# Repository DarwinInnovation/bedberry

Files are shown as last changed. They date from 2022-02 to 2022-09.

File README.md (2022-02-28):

# bedberry

PCB for intelligent electric bed/chair control. A board to allow those with disabilities
a number of ways to control electric beds, chairs etc.

Based around the [Raspberry Pi Zero 2W](https://www.raspberrypi.com/products/raspberry-pi-zero-2-w/) it is designed to allow abilities such as:

- Voice service (e.g. Alexa) control of the bed.
- Control of all the bed's function from simple buttons or pressure pads.
- Link to BLE tilt sensors to allow bed position 'presets'.
- Control of other devices via bluetooth, IR or WiFi, including TVs, lights, SwitchBots etc.

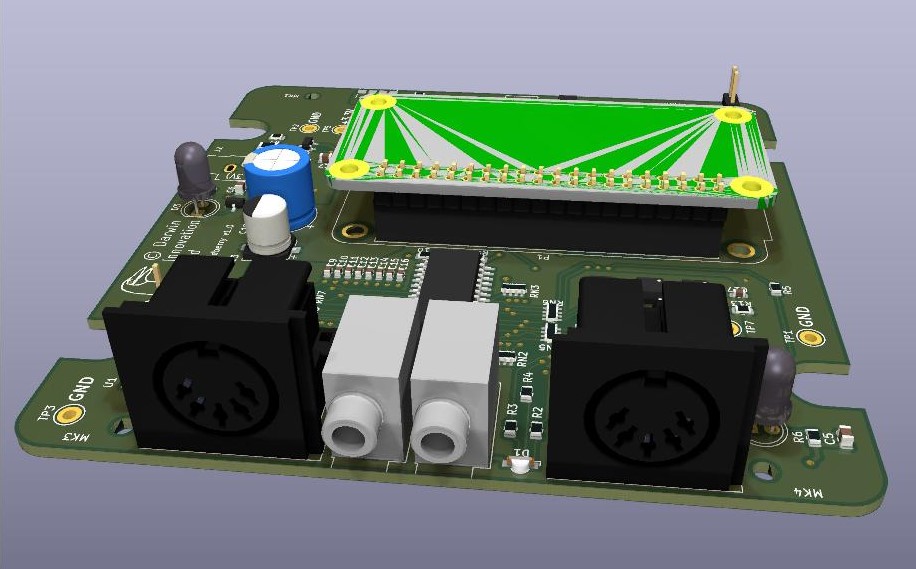
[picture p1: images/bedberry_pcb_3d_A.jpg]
3D Render of PCB


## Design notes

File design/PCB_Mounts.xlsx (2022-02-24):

Origin | 200 | 150
Case |  |  | 10.16
Diff Inch | 2.4 | 3.6
Diff mm | 60.96 | 91.44
 | 169.52 | 104.28
 | 230.48 | 104.28
 | b | 195.72
 | 230.48 | 195.72
PCB
Diff Inch | 3.6 | 2.9
Diff mm | 91.44 | 73.66
 | 154.28 | 113.17
 | 245.72 | 113.17
 | 154.28 | 186.83
 | 245.72 | 186.83

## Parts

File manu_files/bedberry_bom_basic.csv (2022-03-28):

Ref | Qnty | Value | Footprint | Description | MPN
C1, | 1 | 1nF 0805 | Capacitor_SMD:C_0805_2012Metric | Unpolarized capacitor, small symbol
C2, C4, C8, C9, C10, C11, C12, C13, C14, C15, C16, C17, C18, C20, | 14 | 100nF 0603 | Capacitor_SMD:C_0603_1608Metric | Unpolarized capacitor, small symbol
D1, | 1 | KPFA-3010RGBC-11 | LED_SMD:LED_Kingbright_APFA3010_3x1.5mm_Horizontal | LED RGB, Common Anode, SMD, 3.0x1.5mm, Horizontal | KPFA-3010RGBC-11
F1, | 1 | MP005240 | Fuse:Fuse_1812_4532Metric | Resettable fuse, polymeric positive temperature coefficient, small symbol | MP005240
F2, | 1 | 1206L150THWR | Fuse:Fuse_1206_3216Metric | Resettable fuse, polymeric positive temperature coefficient, small symbol | 1206L150THWR
J1, | 1 | USB Micro-B | Connector_USB:USB_Micro-B_Amphenol_10118194_Horizontal | USB Micro Type B connector | 10118194-0001LF
JP1, | 1 | Jumper | Connector_PinHeader_2.54mm:PinHeader_1x03_P2.54mm_Vertical | Jumper, 3-pole, pins 1+2 closed/bridged | M20-8770342
JP2, | 1 | Jumper_2_Open | Connector_PinHeader_2.54mm:PinHeader_1x02_P2.54mm_Vertical | Jumper, 2-pole, open
Q1, Q3, | 2 | BC817 SOT23 | Package_TO_SOT_SMD:SOT-23 | 0.8A Ic, 45V Vce, NPN Transistor, SOT-23 | BC817-25LT1G
Q2, | 1 | MOSFET P-Ch SOT23 | Package_TO_SOT_SMD:SOT-23 | -6.4A Id, -40V Vds, P-Channel MOSFET, SOT-223 | DMG2307L-7
R1, R13, R15, | 3 | 1M 0805 | Resistor_SMD:R_0805_2012Metric | Resistor
R2, | 1 | 120 0805 | Resistor_SMD:R_0805_2012Metric | Resistor
R3, R4, R6, R9, R14, | 5 | 5.6 0805 | Resistor_SMD:R_0805_2012Metric | Resistor
R5, R8, R16, R17, R18, | 5 | 1k 0805 | Resistor_SMD:R_0805_2012Metric | Resistor
R7, R10, R11, R12, | 4 | 10k 0805 | Resistor_SMD:R_0805_2012Metric | Resistor
RN1, RN2, RN3, RN4, | 4 | 10k 4x0603 | Resistor_SMD:R_Array_Concave_4x0603 | 4 resistor network, parallel topology | EXBV8V103JV
RN5, RN6, RN7, RN8, | 4 | 1.5k 4x0603 | Resistor_SMD:R_Array_Concave_4x0603 | 4 resistor network, parallel topology | EXB-38V152JV
U2, | 1 | MCP23017-E/SO | Package_SO:SOIC-28W_7.5x17.9mm_P1.27mm | 16-bit I/O expander, I2C, interrupts, w pull-ups, SSOP-28 | MCP23017-E/SO
U3, U4, U5, U6, U7, U8, U9, U10, | 8 | CPC1017N | Package_SO:SOP-4_3.8x4.1mm_P2.54mm | Form A, Solid State Relay (Photo MOSFET) 60V, 0.1A, 16Ohm, SO-4 | CPC1017NTR
U11, | 1 | CAT24C128 | Package_SO:SOIC-8_3.9x4.9mm_P1.27mm | 128 kb CMOS Serial EEPROM, SOIC-8/TSSOP-8/DFN-8 | CAT24C128WI-GT3

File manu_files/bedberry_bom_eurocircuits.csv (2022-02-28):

Source: | D:\Projects\bedberry\kicad\bedberry.kicad_sch
Date: | 28/02/2022 17:05:20
Tool: | Eeschema (6.0.1)
Generator: | C:\Users\richa\Documents\KiCad\6.0\scripting\plugins/bom_csv_eurocircuits.py
Component Count: | 87
Ref | Qnty | Value | Cmp name | Footprint | Description | Vendor
C1, | 1 | 1nF 0805 | GPC0805102 | Capacitor_SMD:C_0805_2012Metric | Unpolarized capacitor, small symbol
C2, C4, C8, C9, C10, C11, C12, C13, C14, C15, C16, C17, C18, C20, | 14 | 100nF 0603 | GPC0603104 | Capacitor_SMD:C_0603_1608Metric | Unpolarized capacitor, small symbol
C3, | 1 | 100uF SMD | C_Polarized_Small | Capacitor_SMD:CP_Elec_6.3x7.7 | Polarized capacitor, small symbol
C5, C6, C7, | 3 | 1uF 0805 | GPC0805105 | Capacitor_SMD:C_0805_2012Metric | Unpolarized capacitor, small symbol
C19, | 1 | 100uF 10mm TH | C_Polarized_Small | Capacitor_THT:CP_Radial_D10.0mm_P5.00mm | Polarized capacitor, small symbol
D1, | 1 | KPFA-3010RGBC-11 | KPFA-3010RGBC-11 | LED_SMD:LED_Kingbright_APFA3010_3x1.5mm_Horizontal | LED RGB, Common Anode, SMD, 3.0x1.5mm, Horizontal
D2, D3, | 2 | SFH4546 | LTE-4206 | LED_THT:LED_D5.0mm_IRGrey | High-Power IR LED 940nm
F1, | 1 | MP005240 | MP005240 | Fuse:Fuse_1812_4532Metric | Resettable fuse, polymeric positive temperature coefficient, small symbol
F2, | 1 | 1206L150THWR | 1206L150THWR | Fuse:Fuse_1206_3216Metric | Resettable fuse, polymeric positive temperature coefficient, small symbol
J1, | 1 | USB Micro-B | 10118194-0001LF | Connector_USB:USB_Micro-B_Amphenol_10118194_Horizontal | USB Micro Type B connector
J2, J5, J6, J7, | 4 | SJ1-3533NG | SJ1-3533NG | Connector_Audio:Jack_3.5mm_CUI_SJ1-3533NG_Horizontal | Audio Jack, 3 Poles (Stereo / TRS)
J3, J4, | 2 | DIN-7 | PSG03465 | wheelberry:pro-signal_DIN7_Socket | 7-pin DIN connector
JP1, | 1 | Jumper | M20-8770342 | Connector_PinHeader_2.54mm:PinHeader_1x03_P2.54mm_Vertical | Jumper, 3-pole, pins 1+2 closed/bridged
JP2, | 1 | Jumper_2_Open | Jumper_2_Open | Connector_PinHeader_2.54mm:PinHeader_1x02_P2.54mm_Vertical | Jumper, 2-pole, open
MK1, MK2, MK3, MK4, | 4 | M2.5 | MountingHole | MountingHole:MountingHole_2.7mm_M2.5 | Mounting Hole without connection
P1, | 1 | RPi Zero 2 W | A-BL254-DG-G40D | wheelberry:Raspberry_Pi_Zero_2W_Socketed_THT_FaceDown_MountingHoles | Generic connector, double row, 02x20, odd/even pin numbering scheme (row 1 odd numbers, row 2 even numbers), script generated (kicad-library-utils/schlib/autogen/connector/)
Q1, Q3, | 2 | BC817 | BC817-25LT1G | Package_TO_SOT_SMD:SOT-23 | 0.8A Ic, 45V Vce, NPN Transistor, SOT-23
Q2, | 1 | MOSFET P-Ch | DMG2307L | Package_TO_SOT_SMD:SOT-23 | -6.4A Id, -40V Vds, P-Channel MOSFET, SOT-223
R1, R13, R15, | 3 | 1M | GPR08051M | Resistor_SMD:R_0805_2012Metric | Resistor
R2, | 1 | 120 | GPR0805120R | Resistor_SMD:R_0805_2012Metric | Resistor
R3, R4, R6, R9, R14, | 5 | 5.6 | GPR08055R6 | Resistor_SMD:R_0805_2012Metric | Resistor
R5, R8, R16, R17, R18, | 5 | 1k | GPR08051K | Resistor_SMD:R_0805_2012Metric | Resistor
R7, R10, R11, R12, | 4 | 10k | GPR080510K | Resistor_SMD:R_0805_2012Metric | Resistor
RN1, RN2, RN3, RN4, | 4 | 10k | EXBV8V103JV | Resistor_SMD:R_Array_Concave_4x0603 | 4 resistor network, parallel topology
RN5, RN6, RN7, RN8, | 4 | 1.5k | EXB-38V152JV | Resistor_SMD:R_Array_Concave_4x0603 | 4 resistor network, parallel topology
TP1, TP2, TP3, TP4, TP5, TP6, TP7, TP8, | 8 | TestPoint | 5006 | TestPoint:TestPoint_Keystone_5005-5009_Compact | test point
U1, | 1 | TSOP382xx | TSOP38238 | OptoDevice:Vishay_MINICAST-3Pin | Photo Modules for PCM Remote Control Systems
U2, | 1 | MCP23017-E/SO | MCP23017-E/SO | Package_SO:SOIC-28W_7.5x17.9mm_P1.27mm | 16-bit I/O expander, I2C, interrupts, w pull-ups, SSOP-28
U3, U4, U5, U6, U7, U8, U9, U10, | 8 | CPC1017N | CPC1017NTR | Package_SO:SOP-4_3.8x4.1mm_P2.54mm | Form A, Solid State Relay (Photo MOSFET) 60V, 0.1A, 16Ohm, SO-4
U11, | 1 | CAT24C128 | CAT24C128WI-GT3 | Package_SO:SOIC-8_3.9x4.9mm_P1.27mm | 128 kb CMOS Serial EEPROM, SOIC-8/TSSOP-8/DFN-8

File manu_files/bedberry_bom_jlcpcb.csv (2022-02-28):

Comment | Designator | Footprint | LCSC
1nF 0805 | C1 | Capacitor_SMD:C_0805_2012Metric | C46653
100nF 0603 | C2, C4, C9, C10, C11, C12, C13, C14, C15, C16, C17, C18, C20 | Capacitor_SMD:C_0603_1608Metric | C14663
100uF SMD | C3 | Capacitor_SMD:CP_Elec_6.3x7.7
1uF 0805 | C5, C6, C7 | Capacitor_SMD:C_0805_2012Metric | C28323
100nF 0603 | C8 | Capacitor_SMD:C_0603_1608Metric | C14663
100uF 10mm TH | C19 | Capacitor_THT:CP_Radial_D10.0mm_P5.00mm
KPFA-3010RGBC-11 | D1 | LED_SMD:LED_Kingbright_APFA3010_3x1.5mm_Horizontal
SFH4546 | D2, D3 | LED_THT:LED_D5.0mm_IRGrey
MP005240 | F1 | Fuse:Fuse_1812_4532Metric | C55996
1206L150THWR | F2 | Fuse:Fuse_1206_3216Metric | C209741
USB Micro-B | J1 | Connector_USB:USB_Micro-B_Amphenol_10118194_Horizontal | C132563
SJ1-3533NG | J2, J5, J6 | Connector_Audio:Jack_3.5mm_CUI_SJ1-3533NG_Horizontal
DIN-7 | J3, J4 | wheelberry:pro-signal_DIN7_Socket
SJ1-3533NG | J7 | Connector_Audio:Jack_3.5mm_CUI_SJ1-3533NG_Horizontal
Jumper | JP1 | Connector_PinHeader_2.54mm:PinHeader_1x03_P2.54mm_Vertical
Jumper_2_Open | JP2 | Connector_PinHeader_2.54mm:PinHeader_1x02_P2.54mm_Vertical
M2.5 | MK1, MK2, MK3, MK4 | MountingHole:MountingHole_2.7mm_M2.5
RPi Zero 2 W | P1 | wheelberry:Raspberry_Pi_Zero_2W_Socketed_THT_FaceDown_MountingHoles
BC817 | Q1, Q3 | Package_TO_SOT_SMD:SOT-23 | C39828
MOSFET P-Ch | Q2 | Package_TO_SOT_SMD:SOT-23 | C102620
1M | R1, R13, R15 | Resistor_SMD:R_0805_2012Metric | C17514
120 | R2 | Resistor_SMD:R_0805_2012Metric | C17437
5.6 | R3, R4, R6, R9, R14 | Resistor_SMD:R_0805_2012Metric | C25321
1k | R5, R8, R16, R17, R18 | Resistor_SMD:R_0805_2012Metric | C17513
10k | R7, R10, R11, R12 | Resistor_SMD:R_0805_2012Metric | C17414
10k | RN1, RN2, RN3, RN4 | Resistor_SMD:R_Array_Concave_4x0603 | C109324
1.5k | RN5, RN6, RN7, RN8 | Resistor_SMD:R_Array_Concave_4x0603 | C11988
TestPoint | TP1, TP2, TP3, TP4, TP5, TP6, TP7, TP8 | TestPoint:TestPoint_Keystone_5005-5009_Compact
TSOP382xx | U1 | OptoDevice:Vishay_MINICAST-3Pin
MCP23017-E/SO | U2 | Package_SO:SOIC-28W_7.5x17.9mm_P1.27mm
CPC1017N | U3, U4, U5, U6, U7, U8, U9, U10 | Package_SO:SOP-4_3.8x4.1mm_P2.54mm | C81521
CAT24C128 | U11 | Package_SO:SOIC-8_3.9x4.9mm_P1.27mm | C81195

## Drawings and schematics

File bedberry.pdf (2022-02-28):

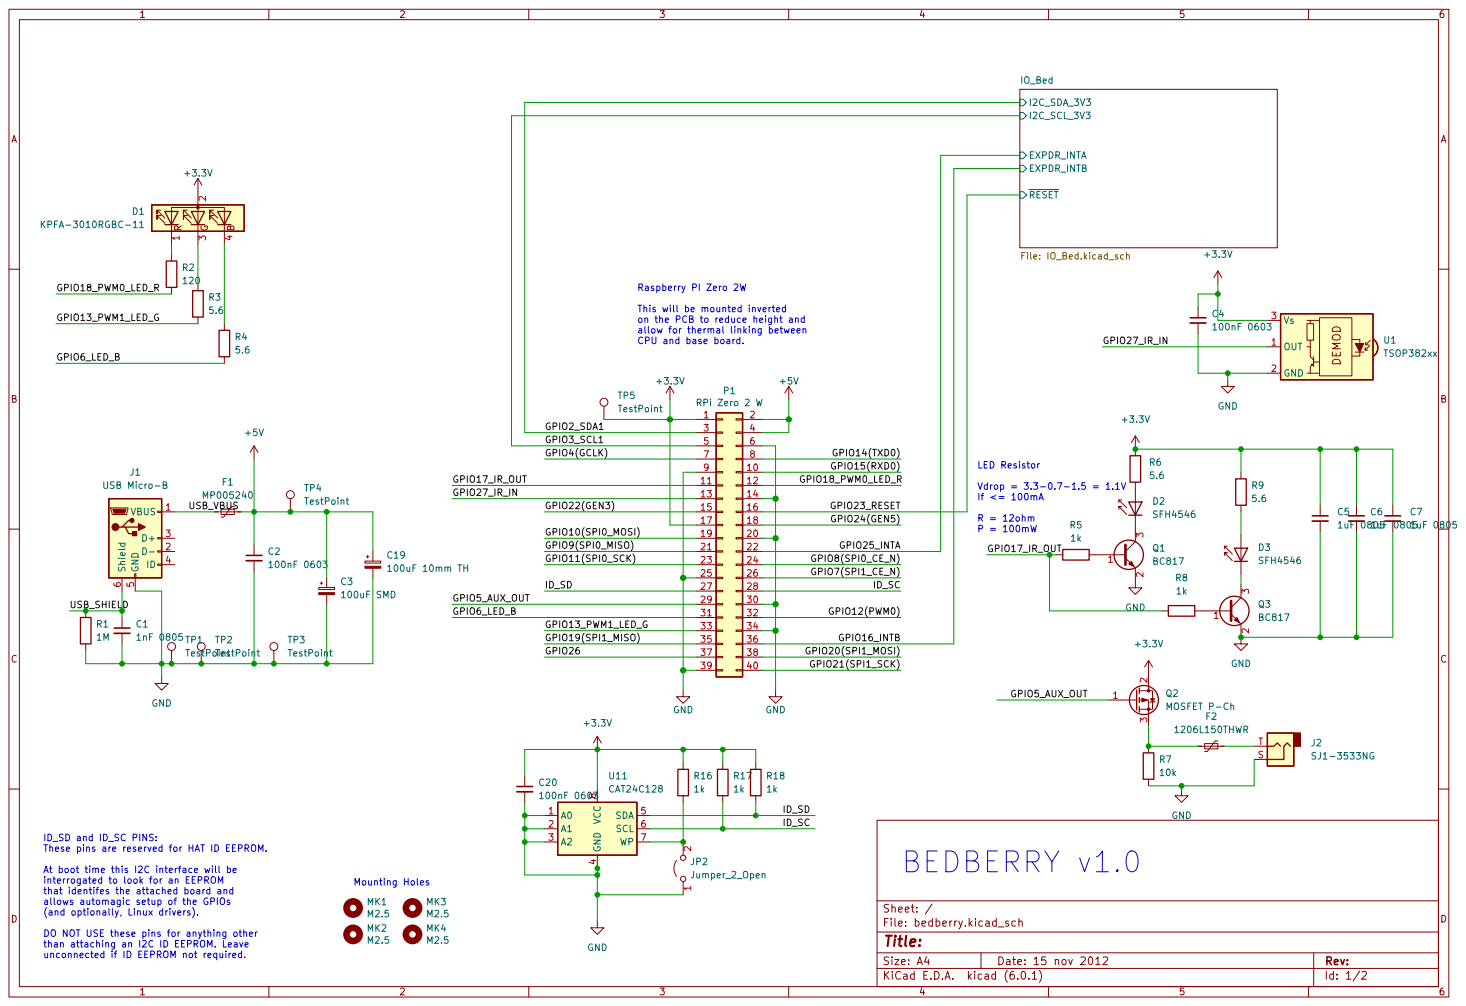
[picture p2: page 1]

This will be mounted inverted
on the PCB to reduce height and
+3.3VGND

4 SDA 5 SCL 6 WP 7 VCC

ID_SD and ID_SC PINS: These pins are reserved for HAT ID EEPROM. At boot time this I2C interface will be

interrogated to look for an EEPROM
that identifes the attached board and
allows automagic setup of the GPIOs
(and optionally, Linux drivers).
DO NOT USE these pins for anything other
than attaching an I2C ID EEPROM. Leave
unconnected if ID EEPROM not required.

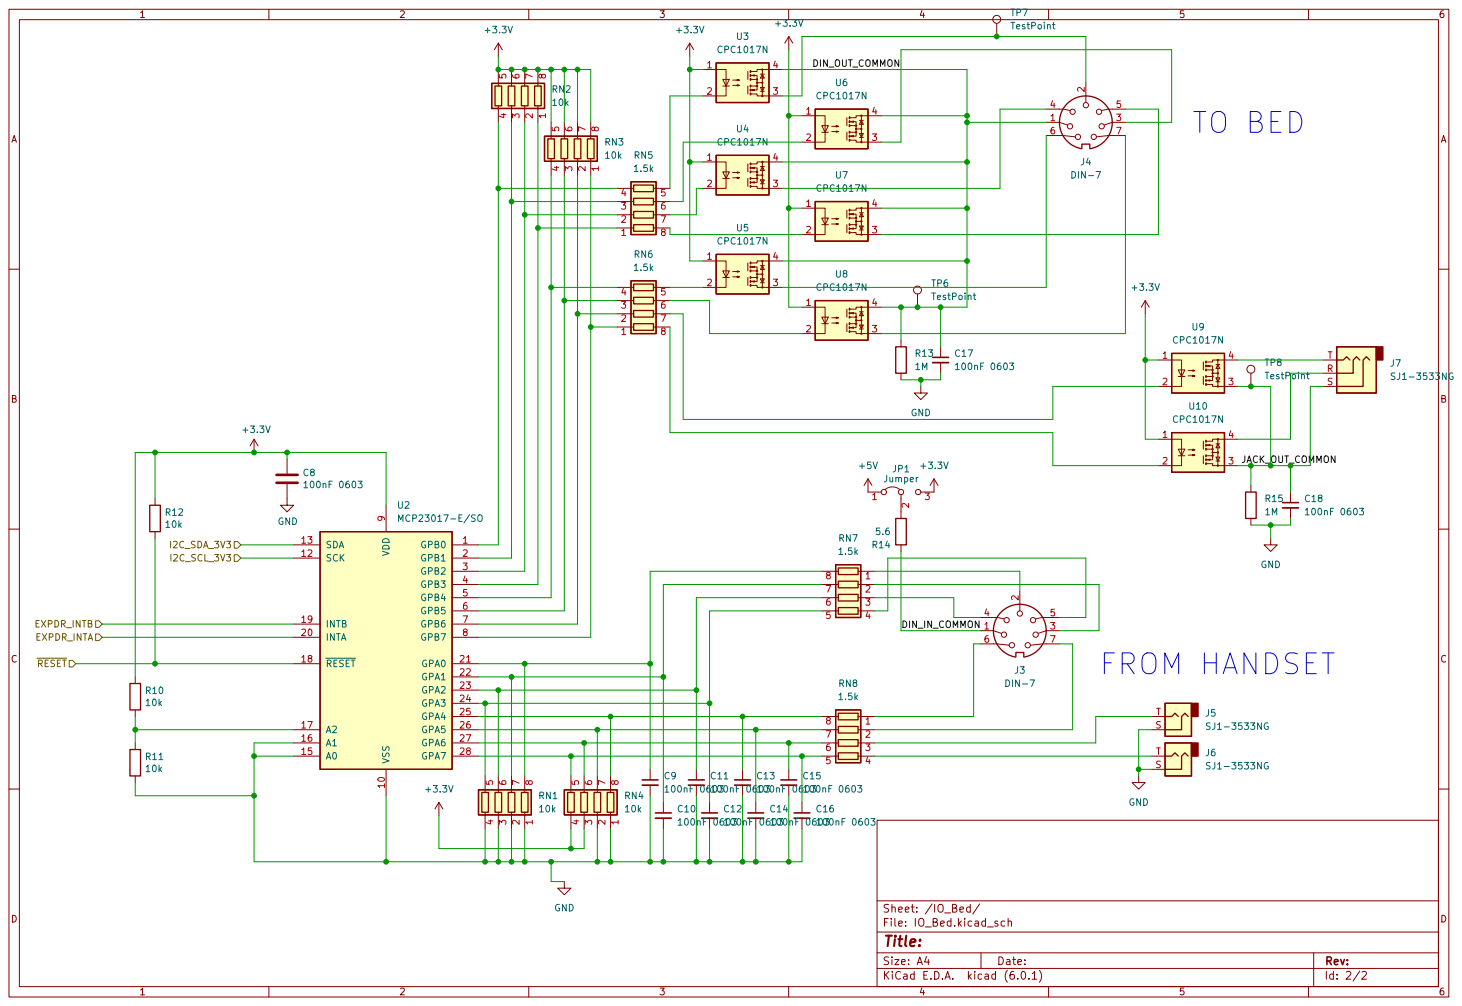
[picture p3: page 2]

4 U7 CPC1017N

4 U8 CPC1017N

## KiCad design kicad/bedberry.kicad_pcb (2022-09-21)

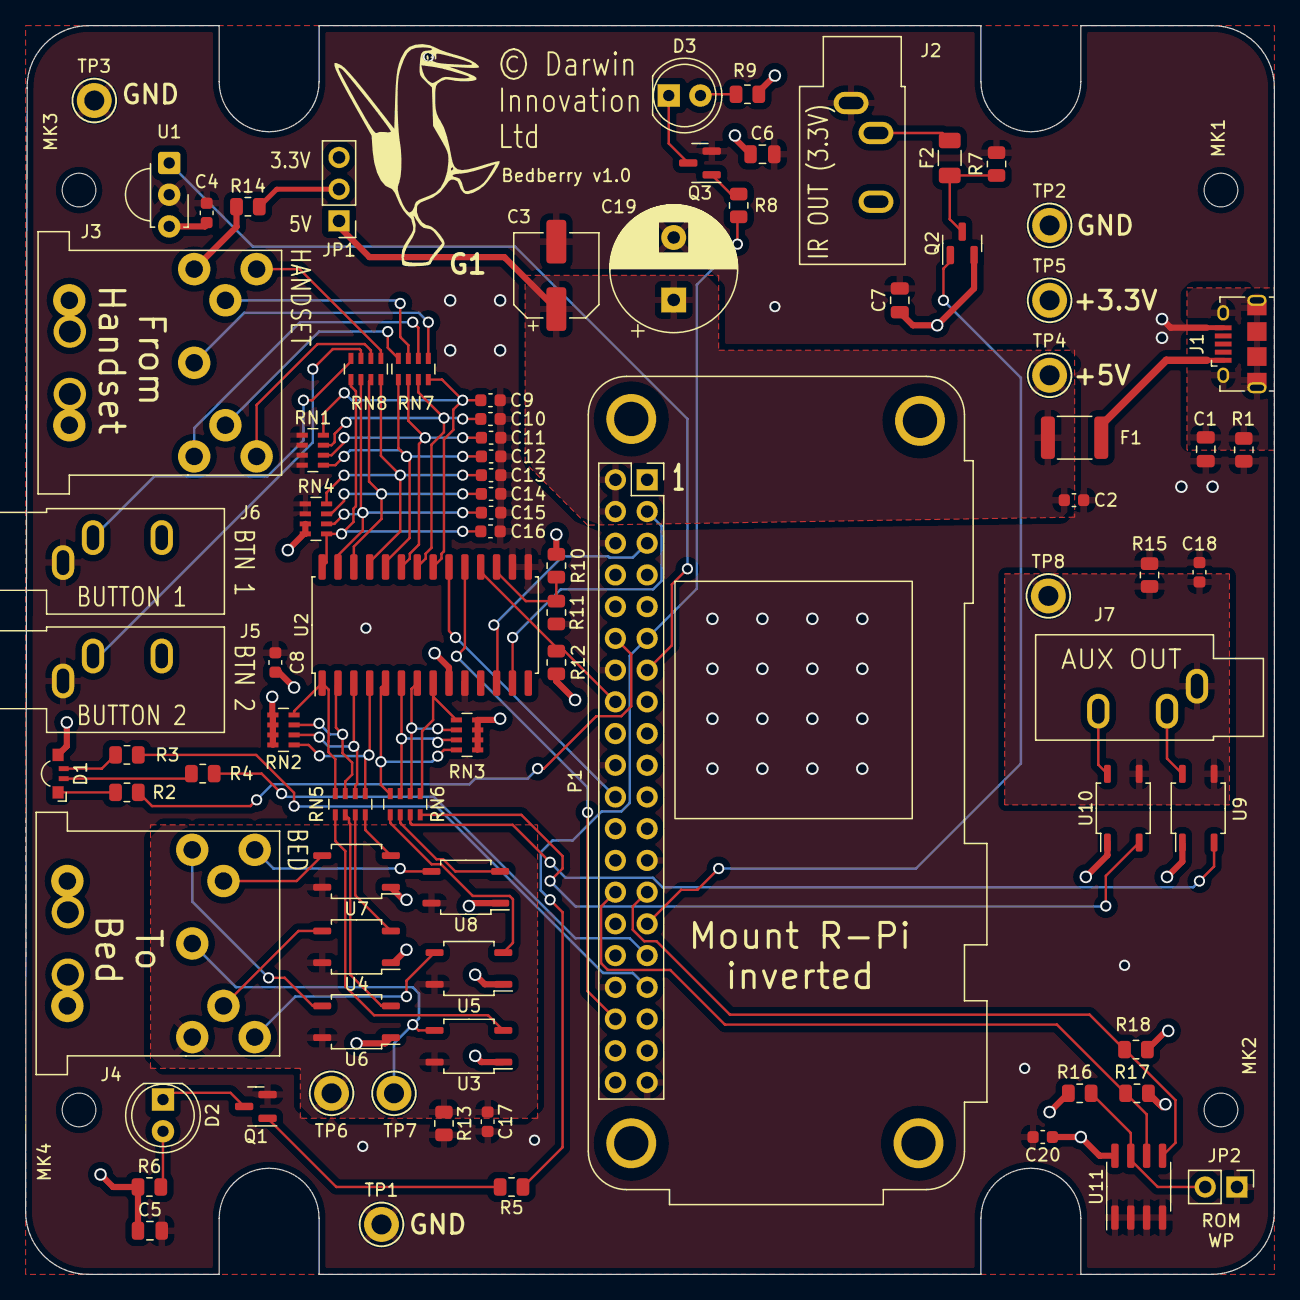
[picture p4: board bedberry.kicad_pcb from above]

Board: 4 copper layers, 100.0 x 100.0 mm, 88 parts (0 on the bottom side), 75 nets.

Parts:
C1: 1nF 0805; C_0805_2012Metric
C2, C4, C8, C9, C10, C11, C12, C13, C14, C15, C16, C17, C18, C20: 100nF 0603; C_0603_1608Metric
C3: 100uF SMD; CP_Elec_6.3x7.7
C5, C6, C7: 1uF 0805; C_0805_2012Metric
C19: 100uF 10mm TH; CP_Radial_D10.0mm_P5.00mm
D1: KPFA-3010RGBC-11; LED_Kingbright_APFA3010_3x1.5mm_Horizontal
D2, D3: SFH4546; LED_D5.0mm_IRGrey
F1: MP005240; Fuse_1812_4532Metric
F2: 1206L150THWR; Fuse_1206_3216Metric
G1: LOGO; darwin_innovation_logo
J1: USB Micro-B; USB_Micro-B_Amphenol_10118194_Horizontal
J2, J5, J6, J7: SJ1-3533NG; Jack_3.5mm_CUI_SJ1-3533NG_Horizontal
J3, J4: DIN-7; pro-signal_DIN7_Socket
JP1: Jumper; PinHeader_1x03_P2.54mm_Vertical
JP2: Jumper_2_Open; PinHeader_1x02_P2.54mm_Vertical
MK1, MK2, MK3, MK4: M2.5; MountingHole_2.7mm_M2.5
P1: RPi Zero 2 W; Raspberry_Pi_Zero_2W_Socketed_THT_FaceDown_MountingHoles
Q1, Q3: BC817; SOT-23
Q2: MOSFET P-Ch; SOT-23
R1, R13, R15: 1M; R_0805_2012Metric
R2: 120; R_0805_2012Metric
R3, R4, R6, R9, R14: 5.6; R_0805_2012Metric
R5, R8, R16, R17, R18: 1k; R_0805_2012Metric
R7, R10, R11, R12: 10k; R_0805_2012Metric
RN1, RN2, RN3, RN4: 10k; R_Array_Concave_4x0603
RN5, RN6, RN7, RN8: 1.5k; R_Array_Concave_4x0603
TP1, TP2, TP3, TP4, TP5, TP6, TP7, TP8: TestPoint; TestPoint_Keystone_5005-5009_Compact
U1: TSOP382xx; Vishay_MINICAST-3Pin
U2: MCP23017-E/SO; SOIC-28W_7.5x17.9mm_P1.27mm
U3, U4, U5, U6, U7, U8, U9, U10: CPC1017N; SOP-4_3.8x4.1mm_P2.54mm
U11: CAT24C128; SOIC-8_3.9x4.9mm_P1.27mm

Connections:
+3V3: C4.1, C5.1, C6.1, C7.1, C8.1, C20.1, D1.2 (A), JP1.3 (B), P1.1, P1.17, Q2.2 (D), R6.1, R9.1, R10.1, R12.1, R16.1, R17.1, R18.1, RN2.5 (R4.2), RN2.6 (R3.2), RN2.7 (R2.2), RN2.8 (R1.2), RN3.5 (R4.2), RN3.6 (R3.2), RN3.7 (R2.2), RN3.8 (R1.2), RN4.3 (R3.1), RN4.4 (R4.1), TP5.1, U1.3 (Vs), U2.9 (VDD), U3.1, U4.1, U5.1, U6.1, U7.1, U8.1, U9.1, U10.1, U11.8 (VCC)
+5V: C2.1, C3.1, C19.1, F1.2, JP1.1 (A), P1.2, P1.4, TP4.1
/GPIO2_SDA1: P1.3, U2.13 (SDA)
/GPIO3_SCL1: P1.5, U2.12 (SCK)
/GPIO5_AUX_OUT: P1.29, Q2.1 (G)
/GPIO6_LED_B: P1.31, R4.2
/GPIO13_PWM1_LED_G: P1.33, R3.2
/GPIO16_INTB: P1.36, U2.19 (INTB)
/GPIO17_IR_OUT: P1.11, R5.1, R8.1
/GPIO18_PWM0_LED_R: P1.12, R2.2
/GPIO23_RESET: P1.16, R12.2, U2.18 (~RESET)
/GPIO25_INTA: P1.22, U2.20 (INTA)
/GPIO27_IR_IN: P1.13, U1.1 (OUT)
/ID_SC: P1.28, R17.2, U11.6 (SCL)
/ID_SD: P1.27, R18.2, U11.5 (SDA)
/IO_Bed/DIN_IN_COMMON: J3.1, R14.1
/IO_Bed/DIN_OUT_COMMON: C17.1, J4.1, R13.1, TP6.1, U3.4, U4.4, U5.4, U6.4, U7.4, U8.4
/IO_Bed/JACK_OUT_COMMON: C18.1, J7.S, R15.1, TP8.1, U9.3, U10.3
/USB_SHIELD: C1.1, J1.6 (Shield), R1.1
/USB_VBUS: F1.1, J1.1 (VBUS)
GND: C1.2, C2.2, C3.2, C4.2, C5.2, C6.2, C7.2, C8.2, C9.2, C10.2, C11.2, C12.2, C13.2, C14.2, C15.2, C16.2, C17.2, C18.2, C19.2, C20.2, J1.5 (GND), J2.S, J5.S, J6.S, JP2.1 (A), P1.6, P1.9, P1.14, P1.20, P1.25, P1.30, P1.34, P1.39, Q1.2 (E), Q3.2 (E), R1.2, R7.2, R11.2, R13.2, R15.2, RN1.1 (R1.1), RN1.2 (R2.1), RN1.3 (R3.1), RN1.4 (R4.1), RN4.1 (R1.1), RN4.2 (R2.1), TP1.1, TP2.1, TP3.1, U1.2 (GND), U2.10 (VSS), U2.15 (A0), U2.16 (A1), U11.1 (A0), U11.2 (A1), U11.3 (A2), U11.4 (GND)
unnamed: C9.1, RN1.8 (R1.2), RN7.8 (R1.2), U2.21 (GPA0)
unnamed: C10.1, RN1.7 (R2.2), RN7.7 (R2.2), U2.22 (GPA1)
unnamed: C11.1, RN1.6 (R3.2), RN7.6 (R3.2), U2.23 (GPA2)
unnamed: C12.1, RN1.5 (R4.2), RN7.5 (R4.2), U2.24 (GPA3)
unnamed: C13.1, RN4.8 (R1.2), RN8.8 (R1.2), U2.25 (GPA4)
unnamed: C14.1, RN4.7 (R2.2), RN8.7 (R2.2), U2.26 (GPA5)
unnamed: C15.1, RN4.6 (R3.2), RN8.6 (R3.2), U2.27 (GPA6)
unnamed: C16.1, RN4.5 (R4.2), RN8.5 (R4.2), U2.28 (GPA7)
unnamed: D2.1 (K), Q1.3 (C)
unnamed: D2.2 (A), R6.2
unnamed: D3.1 (K), Q3.3 (C)
unnamed: D3.2 (A), R9.2
unnamed: F2.1, Q2.3 (S), R7.1
unnamed: F2.2, J2.T
unnamed: J3.2, RN7.1 (R1.1)
unnamed: J3.3, RN7.2 (R2.1)
unnamed: J3.4, RN7.3 (R3.1)
unnamed: J3.5, RN7.4 (R4.1)
unnamed: J3.6, RN8.1 (R1.1)
unnamed: J3.7, RN8.2 (R2.1)
unnamed: J4.2, TP7.1, U3.3
unnamed: J4.3, U6.3
unnamed: J4.4, U4.3
unnamed: J4.5, U7.3
unnamed: J4.6, U5.3
unnamed: J4.7, U8.3
unnamed: J5.T, RN8.3 (R3.1)
unnamed: J6.T, RN8.4 (R4.1)
unnamed: J7.R, U10.4
unnamed: J7.T, U9.4
unnamed: JP1.2 (C), R14.2
unnamed: JP2.2 (B), R16.2, U11.7 (WP)
unnamed: Q1.1 (B), R5.2
unnamed: Q3.1 (B), R8.2
unnamed: D1.1 (R), R2.1
unnamed: D1.3 (G), R3.1
unnamed: D1.4 (B), R4.1
unnamed: R10.2, R11.1, U2.17 (A2)
unnamed: RN2.1 (R1.1), RN5.1 (R1.1), U2.4 (GPB3)
unnamed: RN2.2 (R2.1), RN5.2 (R2.1), U2.3 (GPB2)
unnamed: RN2.3 (R3.1), RN5.3 (R3.1), U2.2 (GPB1)
unnamed: RN2.4 (R4.1), RN5.4 (R4.1), U2.1 (GPB0)
unnamed: RN3.1 (R1.1), RN6.1 (R1.1), U2.8 (GPB7)
unnamed: RN3.2 (R2.1), RN6.2 (R2.1), U2.7 (GPB6)
unnamed: RN3.3 (R3.1), RN6.3 (R3.1), U2.6 (GPB5)
unnamed: RN3.4 (R4.1), RN6.4 (R4.1), U2.5 (GPB4)
unnamed: RN5.5 (R4.2), U3.2
unnamed: RN5.6 (R3.2), U6.2
unnamed: RN5.7 (R2.2), U4.2
unnamed: RN5.8 (R1.2), U7.2
unnamed: RN6.5 (R4.2), U5.2
unnamed: RN6.6 (R3.2), U8.2
unnamed: RN6.7 (R2.2), U9.2
unnamed: RN6.8 (R1.2), U10.2

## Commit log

2022-02-24 Add KiCad files
    [IO_Bed.kicad_sch, PCB_Mounts.xlsx, bedberry.kicad_pcb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]
2022-02-24 Small updates/descriptions
    [IO_Bed.kicad_sch, bedberry.kicad_pcb, bedberry.kicad_sch]
2022-02-28 updated design
    [IO_Bed.kicad_sch, bedberry.kicad_pcb, bedberry.kicad_sch]
2022-02-28 add manufacturing files
    [bedberry_bom_eurocircuits.csv, bedberry_bom_jlcpcb.csv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]
2022-03-28 BOM changes; RPi thermal gap
    [IO_Bed.kicad_sch, bedberry.kicad_pcb, bedberry.kicad_sch]
2022-03-28 Add basic BoM
    [bedberry_bom_basic.csv]
2022-08-16 pre-relay change
    [bedberry.kicad_pcb]

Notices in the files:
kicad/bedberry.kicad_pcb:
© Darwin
